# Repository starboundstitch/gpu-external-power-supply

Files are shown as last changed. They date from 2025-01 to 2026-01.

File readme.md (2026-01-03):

# GPU External Power Supply

The GPU External Power Supply is a project that aims to replace any computer graphics cards' power delivery system with a completely custom board. This repository contains all code, firmware, and schematics required to build the card as well as documentation on how it works.

The sister repository [geps-app](https://github.com/starboundstitch/geps-app) contains the code for the GUI application.

## Summary

The External GPU Power Card is a designed to seamlessly integrate with existing GPUs. It works by replacing the Vcore and Vmem rails with new power stages that have reduced noise, an increased voltage range, and an increased maximum current which should provide additional stability and performance benefits.

The power supply also allows full control of its voltage characteristics to provide unlimited overclocking potential. The device integrates with our companion application to provide real time monitoring and adjustment using a GUI interface, allowing more informed decisions in the overclocking process to extract as much performance as possible.
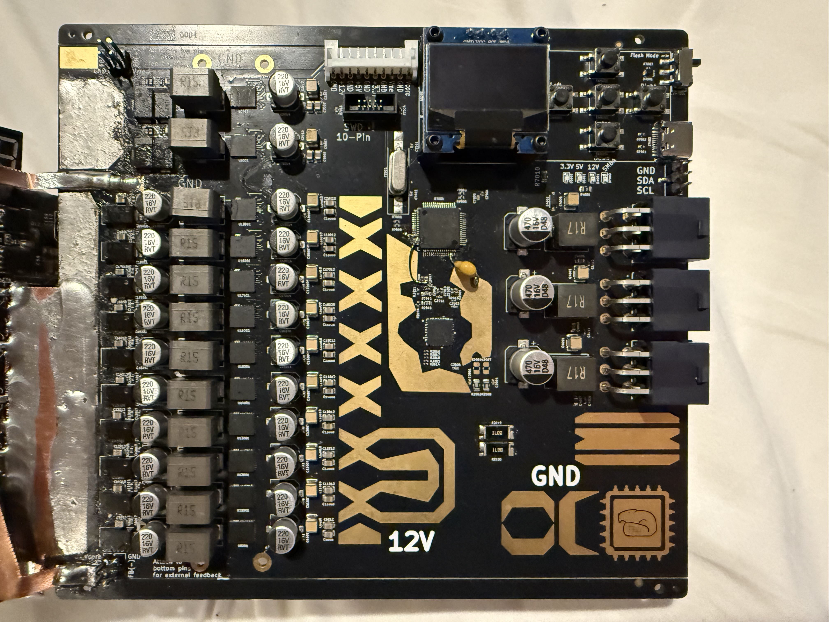
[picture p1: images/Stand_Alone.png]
Image of the device

<div align="center""> 
Prototype 2
</div>

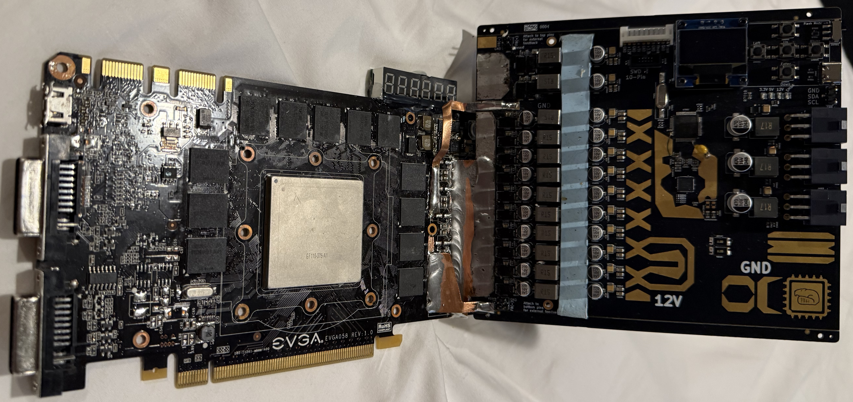
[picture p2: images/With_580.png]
Image of the device attached to a 580

<div align="center""> 
Prototype 2 is attached to a gtx 580
</div>

## Specs

* 12 Phases (10+2)
* Vcore
  * 0-2V
  * 500A Tested
  * 900A Theoretical
  * 10 Phases
* Vcore
  * 0-2.3V
  * 100A Tested
  * 180A Theoretical
  * 2 Phases

## Hardware

This section contains the KICAD project and all the associated files.

We make extensive use of hierarchy in this project and have the following schematics:
* Vcore_stage
  * Single MOSFET that connects to the VRM Controller Vcore Channel
* Vmem_stage
  * Single MOSFET that connects to the VRM Controller Vmem Channel
* VRM_Controller
  * VRM Controller with required pinouts and filtering
* 12V_Supply
  * Input filtering and connectors
* Low_Current_Supply
  * 3.3V & 5V buck converters and LED status
* Onboard_Control
  * Buttons and Display
* U_Controller
  * Microcontroller and required connectors (including USB-C)

## Firmware

This section contains all micro-controller code and is using the rust language with the [stmf4XX-hal](https://github.com/stm32-rs/stm32f4xx-hal) library.

> [!CAUTION]
> The stm32f401RE that is used does NOT have enough SRAM to run in debug mode and it will NOT flash.

The controller should automatically build and flash with:

```
cargo run --release
```

Additionally, in the future we will support flashing via USB DFU mode (instructions TBD).

## License

All the code and hardware files in this repository are licensed according to the GPLv3 in the [LICENSE](https://github.com/starboundstitch/gpu-external-power-supply/blob/master/LICENSE) file.

In addition, many of the symbols and footprints are provided by the manufacturers for use and are thus liable under the manufactures' licenses.

This project was created by [@Xunnin](https://github.com/Xunnin), [@starboundstitch](https://github.com/starboundstitch), and [@StefClef](https://github.com/StefClef).

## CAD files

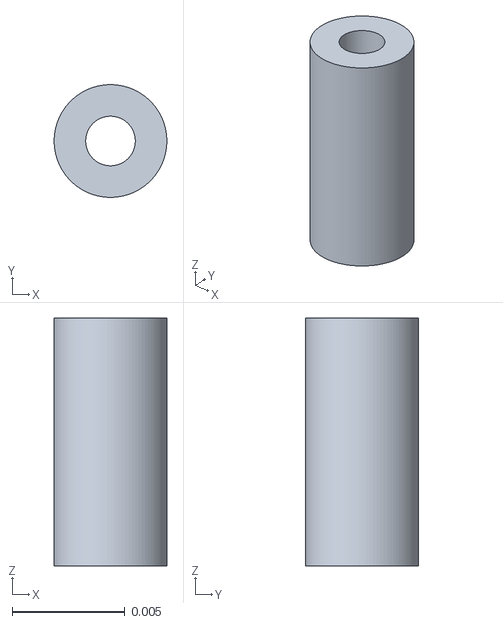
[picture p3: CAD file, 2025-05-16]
prints/DisplayColumn.stl
0.005 x 0.005 x 0.011

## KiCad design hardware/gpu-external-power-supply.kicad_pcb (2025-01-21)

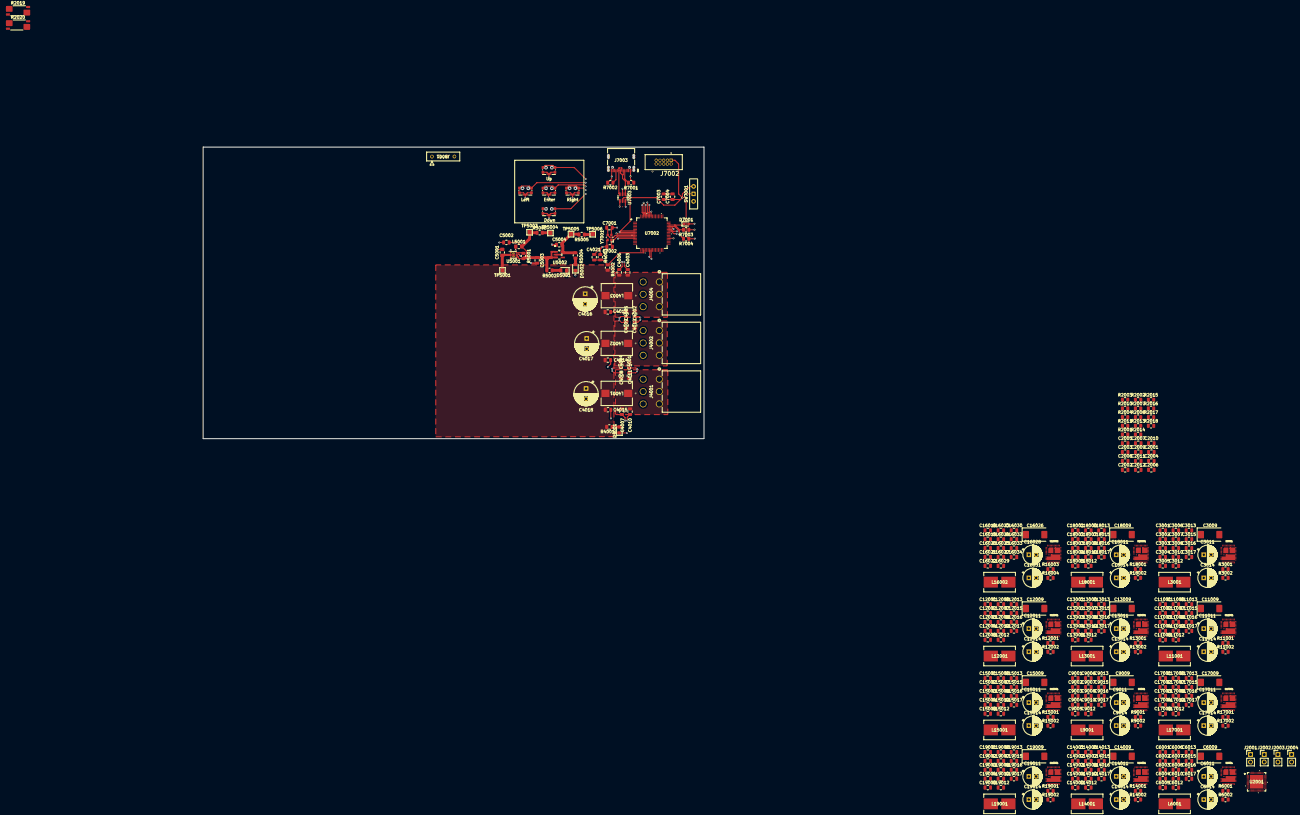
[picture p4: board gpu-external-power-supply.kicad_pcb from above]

Board: 6 copper layers, 170.2 x 99.1 mm, 354 parts (0 on the bottom side), 141 nets.

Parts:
C2001, C2004: 1nF; C_0805_2012Metric
C2002, C2010, C2011, C2012, C5003, C5004: 1uF; C_0805_2012Metric
C2003, C2005: 100pF; C_0805_2012Metric
C2006, C3003, C3006, C3007, C3017, C6003, C6006, C6007, C6017, C9003, C9006, C9007, C9017, C11003, C11006, C11007, C11017, C12003, C12006, C12007, C12017, C13003, C13006, C13007, C13017, C14003, C14006, C14007, C14017, C15003, C15006, C15007, C15017, C16020, C16023, C16024, C16034, C17003, C17006, C17007, C17017, C18003, C18006, C18007, C18017, C19003, C19006, C19007, C19017: 0.1uF; C_0805_2012Metric
C2007, C3016, C6016, C9016, C11016, C12016, C13016, C14016, C15016, C16033, C17016, C18016, C19016: 4.7uF; C_0805_2012Metric
C2008, C2009: 2200pF; C_0805_2012Metric
C3001, C3005, C6001, C6005, C9001, C9005, C11001, C11005, C12001, C12005, C13001, C13005, C14001, C14005, C15001, C15005, C16018, C16022, C17001, C17005, C18001, C18005, C19001, C19005: 47pF; C_0805_2012Metric
C3002, C3004, C6002, C6004, C9002, C9004, C11002, C11004, C12002, C12004, C13002, C13004, C14002, C14004, C15002, C15004, C16019, C16021, C17002, C17004, C18002, C18004, C19002, C19004: 2.2uF; C_0805_2012Metric
C3008, C3010, C3012, C3015, C5002, C6008, C6010, C6012, C6015, C9008, C9010, C9012, C9015, C11008, C11010, C11012, C11015, C12008, C12010, C12012, C12015, C13008, C13010, C13012, C13015, C14008, C14010, C14012, C14015, C15008, C15010, C15012, C15015, C16025, C16027, C16029, C16032, C17008, C17010, C17012, C17015, C18008, C18010, C18012, C18015, C19008, C19010, C19012, C19015: 22uF; C_0805_2012Metric
C3009, C6009, C9009, C11009, C12009, C13009, C14009, C15009, C16026, C17009, C18009, C19009: 470uF; CP_EIA-7343-40_Kemet-Y
C3011, C3014, C6011, C6014, C9011, C9014, C11011, C11014, C12011, C12014, C13011, C13014, C14011, C14014, C15011, C15014, C16028, C16031, C17011, C17014, C18011, C18014, C19011, C19014: 220uF; CP_Radial_D6.3mm_P2.50mm
C3013, C6013, C9013, C11013, C12013, C13013, C14013, C15013, C16030, C17013, C18013, C19013: 47uF; C_0805_2012Metric
C4001, C4002, C4003: 470u; C_0805_2012Metric
C4004, C4005, C4006: 47u; C_0805_2012Metric
C4007, C4008, C4009: 10u; C_0805_2012Metric
C4010, C4011, C4012, C4021: 0.1u; C_0805_2012Metric
C4013, C4014, C4015: 330u; C_0805_2012Metric
C4016, C4017, C4018: 470u; CP_Radial_D8.0mm_P3.50mm
C5001: 10uF; C_0805_2012Metric_Pad1.18x1.45mm_HandSolder
C7001, C7002: 6pF; C_0805_2012Metric
C7003: 4.7u; C_0805_2012Metric
C7004: 100n; C_0805_2012Metric
D4001, D5001, D5002: 150080SS75000; LED_0805_2012Metric_Pad1.15x1.40mm_HandSolder
D7001: GG060303100N2P; D_0603_1608Metric
J2001, J2002, J2003, J2004: Conn_01x02_Pin; PinHeader_1x02_P2.54mm_Vertical
J4001, J4002, J4004: 353180620; CONN_35318-06xx_MOL
J7002: Conn_ARM_JTAG_SWD_10; CNC_3221-10-0100-00
J7003: USB_C_Receptacle_USB2.0_16P; 12402012E212A_AMP
J8001: Conn_01x04_Pin; CONN_PPTC041LFBN-RC_SUL
L3001, L6001, L9001, L11001, L12001, L13001, L14001, L15001, L16002, L17001, L18001, L19001: 150nH; IND_IHVR-4025JZ-3Z_VIS
L4001, L4002, L4003: 170nH; IND_IFLR4031GCERR17M01_VIS-L
L5001: 2.2uH; L_0805_2012Metric_Pad1.15x1.40mm_HandSolder
R2001, R2002, R2007, R2008, R2013, R2014, R2015, R2016, R2017, R2018, R4002: 10k; R_0805_2012Metric
R2003: 130k; R_0805_2012Metric
R2004, R2011: 37.4k; R_0805_2012Metric
R2010: 2430k; R_0805_2012Metric
R2019, R2020: 1m; R_Shunt_Vishay_WSK2512_6332Metric_T1.19mm
R3001, R6001, R9001, R11001, R12001, R13001, R14001, R15001, R16003, R17001, R18001, R19001: 2.2; R_0805_2012Metric
R3002, R6002, R9002, R11002, R12002, R13002, R14002, R15002, R16004, R17002, R18002, R19002: 0; R_0805_2012Metric
R4001: 337; R_0805_2012Metric
R4003: 3.5k; R_0805_2012Metric
R5001, R7004: 100k; R_0805_2012Metric
R5002: 100+-5; R_0805_2012Metric
R5003, R5005: 1; R_0805_2012Metric
R5004: 45+-5; R_0805_2012Metric
R7001, R7002: 5K1; R_0805_2012Metric
R7003: 10K; R_0805_2012Metric
SW7001: SW_Wuerth_450301014042; SW_Slide-03_Wuerth-WS-SLTV_10x2.5x6.4_P2.54mm
SW8001, SW8002, SW8003, SW8004, SW8005: CK_KMS2xxG; SW_SPST_CK_KMS2xxGP
TP5001: 12V -> 5V; TestPoint_Pad_1.5x1.5mm
TP5003, TP5004, TP5005, TP5006: TestPoint; TestPoint_Pad_1.5x1.5mm
U2001: TPS536C7B1RSLT; QFN48_6X6_TEX
U3001, U6001, U9001, U11001, U12001, U13001, U14001, U15001, U16002, U17001, U18001, U19001: AOZ5276QI
U5001: TPS62160DSG; WSON-8-1EP_2x2mm_P0.5mm_EP0.9x1.6mm_ThermalVias
U5002: TPS73633DBVR; DBV5
U7002: STM32C071RBT6; LQFP-64_STM
U7003: USBLC6-2SC6; SOT-23-6
Y7001: Crystal_GND24; Crystal_SMD_Abracon_ABM10-4Pin_2.5x2.0mm

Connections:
3.3V: C2006.1, C2007.1, C7003.1, C7004.1, J7002.1 (VTref), J8001.2, R2001.1, R2007.1, R2013.1, R2014.1, R2015.1, R2016.1, R2017.1, R2018.1, R5005.2, R7004.1, SW7001.3 (A), TP5006.1, U2001.47 (VCC), U7002.7 (VREF+), U7002.8 (VDD/VDDA), U7003.5 (VBUS)
5V: R5003.2, TP5004.1
12V: C4013.1, C4014.1, C4015.1, C4016.1, C4017.1, C4018.1, C5001.1, L4001.2, L4002.2, L4003.2, R4001.1, R4002.1, TP5001.1, U5001.2 (VIN), U5001.3 (EN)
12V_VOL_SENS: C4021.1, R4002.2, R4003.1, U7002.19 (PA2)
/5v: C3002.1, C6002.1, C9002.1, C11002.1, C12002.1, C13002.1, C14002.1, C15002.1, C16019.1, C17002.1, C18002.1, C19002.1, R3001.1, R6001.1, R9001.1, R11001.1, R12001.1, R13001.1, R14001.1, R15001.1, R16003.1, R17001.1, R18001.1, R19001.1, U3001.4 (PVCC), U3001.35 (EN), U6001.4 (PVCC), U6001.35 (EN), U9001.4 (PVCC), U9001.35 (EN), U11001.4 (PVCC), U11001.35 (EN), U12001.4 (PVCC), U12001.35 (EN), U13001.4 (PVCC), U13001.35 (EN), U14001.4 (PVCC), U14001.35 (EN), U15001.4 (PVCC), U15001.35 (EN), U16002.4 (PVCC), U16002.35 (EN), U17001.4 (PVCC), U17001.35 (EN), U18001.4 (PVCC), U18001.35 (EN), U19001.4 (PVCC), U19001.35 (EN)
/U Controller/PF0: C7001.2, U7002.10 (PF0-OSC_IN), Y7001.3
/U Controller/PF1: C7002.2, U7002.11 (PF1-OSC_OUT), Y7001.1
/VRM Controller/ADDR_CONFIG: R2010.2, R2011.1, U2001.42 (ADDR_CONFIG)
/VRM Controller/CSNIN: C2011.2, C2012.1, C3007.1, C3008.1, C3010.1, C3012.1, C3014.1, C6007.1, C6008.1, C6010.1, C6012.1, C6014.1, C9007.1, C9008.1, C9010.1, C9012.1, C9014.1, C11007.1, C11008.1, C11010.1, C11012.1, C11014.1, C12007.1, C12008.1, C12010.1, C12012.1, C12014.1, C13007.1, C13008.1, C13010.1, C13012.1, C13014.1, C14007.1, C14008.1, C14010.1, C14012.1, C14014.1, C15007.1, C15008.1, C15010.1, C15012.1, C15014.1, C16024.1, C16025.1, C16027.1, C16029.1, C16031.1, C17007.1, C17008.1, C17010.1, C17012.1, C17014.1, C18007.1, C18008.1, C18010.1, C18012.1, C18014.1, C19007.1, C19008.1, C19010.1, C19012.1, C19014.1, R2019.1, R2020.2, U2001.46 (VIN_CSNIN), U3001.25 (VIN), U3001.30 (VIN), U6001.25 (VIN), U6001.30 (VIN), U9001.25 (VIN), U9001.30 (VIN), U11001.25 (VIN), U11001.30 (VIN), U12001.25 (VIN), U12001.30 (VIN), U13001.25 (VIN), U13001.30 (VIN), U14001.25 (VIN), U14001.30 (VIN), U15001.25 (VIN), U15001.30 (VIN), U16002.25 (VIN), U16002.30 (VIN), U17001.25 (VIN), U17001.30 (VIN), U18001.25 (VIN), U18001.30 (VIN), U19001.25 (VIN), U19001.30 (VIN)
/VRM Controller/CSPIN: C2010.1, C2011.1, R2019.2, R2020.1, U2001.45 (CSPIN)
/VRM Controller/CUR_A_9: C18001.1, U2001.35 (ACSP9), U18001.38 (IMON)
/VRM Controller/Cur_A_1: C6001.1, U2001.27 (ACSP1), U6001.38 (IMON)
/VRM Controller/Cur_A_2: C11001.1, U2001.28 (ACSP2), U11001.38 (IMON)
/VRM Controller/Cur_A_3: C12001.1, U2001.29 (ACSP3), U12001.38 (IMON)
/VRM Controller/Cur_A_4: C13001.1, U2001.30 (ACSP4), U13001.38 (IMON)
/VRM Controller/Cur_A_5: C14001.1, U2001.31 (ACSP5), U14001.38 (IMON)
/VRM Controller/Cur_A_6: C15001.1, U2001.32 (ACSP6), U15001.38 (IMON)
/VRM Controller/Cur_A_7: C16018.1, U2001.33 (ACSP7), U16002.38 (IMON)
/VRM Controller/Cur_A_8: C17001.1, U2001.34 (ACSP8), U17001.38 (IMON)
/VRM Controller/Cur_A_10: C19001.1, U2001.36 (ACSP10), U19001.38 (IMON)
/VRM Controller/Cur_B_1: C3001.1, U2001.38 (BCSP1), U3001.38 (IMON)
/VRM Controller/Cur_B_2: C9001.1, U2001.37 (BCSP2), U9001.38 (IMON)
/VRM Controller/PWM_A_1: U2001.12 (APWM1), U6001.34 (PWM)
/VRM Controller/PWM_A_2: U2001.11 (APWM2), U11001.34 (PWM)
/VRM Controller/PWM_A_3: U2001.10 (APWM3), U12001.34 (PWM)
/VRM Controller/PWM_A_4: U2001.9 (APWM4), U13001.34 (PWM)
/VRM Controller/PWM_A_5: U2001.8 (APWM5), U14001.34 (PWM)
/VRM Controller/PWM_A_6: U2001.7 (APWM6), U15001.34 (PWM)
/VRM Controller/PWM_A_7: U2001.6 (APWM7), U16002.34 (PWM)
/VRM Controller/PWM_A_8: U2001.5 (APWM8), U17001.34 (PWM)
/VRM Controller/PWM_A_9: U2001.4 (APWM9), U18001.34 (PWM)
/VRM Controller/PWM_A_10: U2001.3 (APWM10), U19001.34 (PWM)
/VRM Controller/PWM_B_1: U2001.1 (BPWM1), U3001.34 (PWM)
/VRM Controller/PWM_B_2: U2001.2 (BPWM2), U9001.34 (PWM)
/VRM Controller/VBOOT_A: R2003.2, R2004.1, U2001.18 (VBOOT_CHA)
/VRM Controller/VREF: C2002.2, C3001.2, C3003.1, C6001.2, C6003.1, C9001.2, C9003.1, C11001.2, C11003.1, C12001.2, C12003.1, C13001.2, C13003.1, C14001.2, C14003.1, C15001.2, C15003.1, C16018.2, C16020.1, C17001.2, C17003.1, C18001.2, C18003.1, C19001.2, C19003.1, R2003.1, R2010.1, U2001.48 (VREF), U3001.39 (REFIN), U6001.39 (REFIN), U9001.39 (REFIN), U11001.39 (REFIN), U12001.39 (REFIN), U13001.39 (REFIN), U14001.39 (REFIN), U15001.39 (REFIN), U16002.39 (REFIN), U17001.39 (REFIN), U18001.39 (REFIN), U19001.39 (REFIN)
AVR_READY: R2015.2, U2001.16 (AVR_RDY), U7002.38 (PC6)
A_ENABLE: C2001.1, R2001.2, R2002.1, U2001.17 (AVR_EN), U7002.49 (PC9)
B_ENABLE: C2004.1, R2007.2, R2008.1, U2001.19 (BVR_EN_/_RESET#_/_SYNC), U7002.64 (PC10)
CORE_TEMO: C2009.1, U2001.43 (BTSEN_/_ATSEN_/_TSEN)
CORE_TEMP: C6005.1, C11005.1, C12005.1, C13005.1, C14005.1, C15005.1, C16022.1, C17005.1, C18005.1, C19005.1, U6001.36 (TMON), U11001.36 (TMON), U12001.36 (TMON), U13001.36 (TMON), U14001.36 (TMON), U15001.36 (TMON), U16002.36 (TMON), U17001.36 (TMON), U18001.36 (TMON), U19001.36 (TMON)
GND: C2001.2, C2002.1, C2004.2, C2006.2, C2007.2, C2008.2, C2009.2, C2010.2, C2012.2, C3002.2, C3003.2, C3004.2, C3005.2, C3007.2, C3008.2, C3009.2, C3010.2, C3011.2, C3012.2, C3013.2, C3014.2, C3015.2, C3016.2, C3017.2, C4001.2, C4002.2, C4003.2, C4004.2, C4005.2, C4006.2, C4007.2, C4008.2, C4009.2, C4010.2, C4011.2, C4012.2, C4013.2, C4014.2, C4015.2, C4016.2, C4017.2, C4018.2, C4021.2, C5001.2, C5002.2, C5003.2, C5004.2, C6002.2, C6003.2, C6004.2, C6005.2, C6007.2, C6008.2, C6009.2, C6010.2, C6011.2, C6012.2, C6013.2, C6014.2, C6015.2, C6016.2, C6017.2, C7001.1, C7002.1, C7003.2, C7004.2, C9002.2, C9003.2, C9004.2, C9005.2, C9007.2, C9008.2, C9009.2, C9010.2, C9011.2, C9012.2, C9013.2, C9014.2, C9015.2, C9016.2, C9017.2, C11002.2, C11003.2, C11004.2, C11005.2, C11007.2, C11008.2, C11009.2, C11010.2, C11011.2, C11012.2, C11013.2, C11014.2, C11015.2, C11016.2, C11017.2, C12002.2, C12003.2, C12004.2, C12005.2, C12007.2, C12008.2, C12009.2, C12010.2, C12011.2, C12012.2, C12013.2, C12014.2, C12015.2, C12016.2, C12017.2, C13002.2, C13003.2, C13004.2, C13005.2, C13007.2, C13008.2, C13009.2, C13010.2, C13011.2, C13012.2, C13013.2, C13014.2, C13015.2, C13016.2, C13017.2, C14002.2, C14003.2, C14004.2, C14005.2, C14007.2, C14008.2, C14009.2, C14010.2, C14011.2, C14012.2, C14013.2, C14014.2, C14015.2, C14016.2, C14017.2, C15002.2, C15003.2, C15004.2, C15005.2, C15007.2, C15008.2, C15009.2, C15010.2, C15011.2, C15012.2, C15013.2, C15014.2, C15015.2, C15016.2, C15017.2, C16019.2, C16020.2, C16021.2, C16022.2, C16024.2, C16025.2, C16026.2, C16027.2, C16028.2, C16029.2, C16030.2, C16031.2, C16032.2, C16033.2, C16034.2, C17002.2, C17003.2, C17004.2, C17005.2, C17007.2, C17008.2, C17009.2, C17010.2, C17011.2, C17012.2, C17013.2, C17014.2, C17015.2, C17016.2, C17017.2, C18002.2, C18003.2, C18004.2, C18005.2, C18007.2, C18008.2, C18009.2, C18010.2, C18011.2, C18012.2, C18013.2, C18014.2, C18015.2, C18016.2, C18017.2, C19002.2, C19003.2, C19004.2, C19005.2, C19007.2, C19008.2, C19009.2, C19010.2, C19011.2, C19012.2, C19013.2, C19014.2, C19015.2, C19016.2, C19017.2, D4001.1 (K), D5001.1 (K), D5002.1 (K), D7001.2 (A), J2002.2, J2004.2, J4001.2, J4001.4, J4001.6, J4002.2, J4002.4, J4002.6, J4004.2, J4004.4, J4004.6, J7002.3 (GND), J7002.5 (GND), J7002.9 (GNDDetect), J7003.A1 (GND), J7003.B1 (GND), J7003.S1 (SHIELD), J8001.1, R2002.2, R2004.2, R2008.2, R2011.2, R4003.2, R7001.2, R7002.2, R7003.1, SW7001.2 (C), SW8001.1, SW8001.SH (B), SW8002.1, SW8002.SH (B), SW8003.1, SW8003.SH (B), SW8004.1, SW8004.SH (B), SW8005.1, SW8005.SH (B), U2001.49 (GND), U3001.2 (AGND), U3001.5 (PGND), U3001.20 (PGND), U3001.40 (PGND), U5001.1 (PGND), U5001.4 (AGND), U5001.5 (FB), U5001.9 (PAD), U5002.2 (GND), U6001.2 (AGND), U6001.5 (PGND), U6001.20 (PGND), U6001.40 (PGND), U7002.9 (VSS/VSSA), U7003.2 (GND), U9001.2 (AGND), U9001.5 (PGND), U9001.20 (PGND), U9001.40 (PGND), U11001.2 (AGND), U11001.5 (PGND), U11001.20 (PGND), U11001.40 (PGND), U12001.2 (AGND), U12001.5 (PGND), U12001.20 (PGND), U12001.40 (PGND), U13001.2 (AGND), U13001.5 (PGND), U13001.20 (PGND), U13001.40 (PGND), U14001.2 (AGND), U14001.5 (PGND), U14001.20 (PGND), U14001.40 (PGND), U15001.2 (AGND), U15001.5 (PGND), U15001.20 (PGND), U15001.40 (PGND), U16002.2 (AGND), U16002.5 (PGND), U16002.20 (PGND), U16002.40 (PGND), U17001.2 (AGND), U17001.5 (PGND), U17001.20 (PGND), U17001.40 (PGND), U18001.2 (AGND), U18001.5 (PGND), U18001.20 (PGND), U18001.40 (PGND), U19001.2 (AGND), U19001.5 (PGND), U19001.20 (PGND), U19001.40 (PGND), Y7001.2, Y7001.4
I2C_SCL: J8001.3, U7002.24 (PA7)
I2C_SDA: J8001.4, U7002.23 (PA6)
MEM_TEMP: C2008.1, C3005.1, C9005.1, U2001.44 (ATSEN_/_BTSEN), U3001.36 (TMON), U9001.36 (TMON)
NRST: J7002.10 (~RESET), U7002.12 (PF2-NRST)
unnamed: C3006.1, R3002.2
unnamed: C3006.2, U3001.31 (PHASE), U3001.32 (PHASE)
unnamed: C4001.1, C4004.1, C4007.1, C4010.1, J4001.1, J4001.3, J4001.5, L4001.1
unnamed: C4002.1, C4005.1, C4008.1, C4011.1, J4002.1, J4002.3, J4002.5, L4002.1
unnamed: C4003.1, C4006.1, C4009.1, C4012.1, J4004.1, J4004.3, J4004.5, L4003.1
unnamed: C6006.1, R6002.2
unnamed: C6006.2, U6001.31 (PHASE), U6001.32 (PHASE)
unnamed: C9006.1, R9002.2
unnamed: C9006.2, U9001.31 (PHASE), U9001.32 (PHASE)
unnamed: C11006.1, R11002.2
unnamed: C11006.2, U11001.31 (PHASE), U11001.32 (PHASE)
unnamed: C12006.1, R12002.2
unnamed: C12006.2, U12001.31 (PHASE), U12001.32 (PHASE)
unnamed: C13006.1, R13002.2
unnamed: C13006.2, U13001.31 (PHASE), U13001.32 (PHASE)
unnamed: C14006.1, R14002.2
unnamed: C14006.2, U14001.31 (PHASE), U14001.32 (PHASE)
unnamed: C15006.1, R15002.2
unnamed: C15006.2, U15001.31 (PHASE), U15001.32 (PHASE)
unnamed: C16023.1, R16004.2
unnamed: C16023.2, U16002.31 (PHASE), U16002.32 (PHASE)
unnamed: C17006.1, R17002.2
unnamed: C17006.2, U17001.31 (PHASE), U17001.32 (PHASE)
unnamed: C18006.1, R18002.2
unnamed: C18006.2, U18001.31 (PHASE), U18001.32 (PHASE)
unnamed: C19006.1, R19002.2
unnamed: C19006.2, U19001.31 (PHASE), U19001.32 (PHASE)
unnamed: D4001.2 (A), R4001.2
unnamed: D5001.2 (A), R5002.2
unnamed: D5002.2 (A), R5004.2
unnamed: C2005.1, J2001.1, U2001.25 (AVSP)
unnamed: C2003.1, J2003.1, U2001.40 (BVSP)
unnamed: C2003.2, J2004.1, U2001.39 (BVSN)
unnamed: J7003.A5 (CC1), R7001.1
unnamed: J7003.B5 (CC2), R7002.1
unnamed: J7003.A6 (D+), J7003.B6 (D+), U7003.3 (I/O2)
unnamed: J7003.A7 (D-), J7003.B7 (D-), U7003.1 (I/O1)
unnamed: J7003.A4 (VBUS), J7003.B4 (VBUS)
unnamed: L3001.1, U3001.10 (VSWH)
unnamed: L6001.1, U6001.10 (VSWH)
unnamed: L9001.1, U9001.10 (VSWH)
unnamed: L11001.1, U11001.10 (VSWH)
unnamed: L12001.1, U12001.10 (VSWH)
unnamed: L13001.1, U13001.10 (VSWH)
unnamed: L14001.1, U14001.10 (VSWH)
unnamed: L15001.1, U15001.10 (VSWH)
unnamed: L16002.1, U16002.10 (VSWH)
unnamed: L17001.1, U17001.10 (VSWH)
unnamed: L18001.1, U18001.10 (VSWH)
unnamed: L19001.1, U19001.10 (VSWH)
unnamed: C2005.2, U2001.26 (AVSN)
unnamed: R3002.1, U3001.33 (BOOT)
unnamed: C3004.1, R3001.2, U3001.3 (VCC)
unnamed: R5001.1, U5001.8 (PG)
unnamed: L5001.1, U5001.7 (SW)
unnamed: C5002.1, C5003.1, L5001.2, R5001.2, R5002.1, R5003.1, TP5003.1, U5001.6 (VOS), U5002.1 (IN), U5002.3 (EN)
unnamed: C5004.1, R5004.1, R5005.1, TP5005.1, U5002.5 (OUT)
unnamed: R6002.1, U6001.33 (BOOT)
unnamed: C6004.1, R6001.2, U6001.3 (VCC)
unnamed: R9002.1, U9001.33 (BOOT)
unnamed: C9004.1, R9001.2, U9001.3 (VCC)
unnamed: R11002.1, U11001.33 (BOOT)
unnamed: C11004.1, R11001.2, U11001.3 (VCC)
unnamed: R12002.1, U12001.33 (BOOT)
unnamed: C12004.1, R12001.2, U12001.3 (VCC)
unnamed: R13002.1, U13001.33 (BOOT)
unnamed: C13004.1, R13001.2, U13001.3 (VCC)
unnamed: R14002.1, U14001.33 (BOOT)
unnamed: C14004.1, R14001.2, U14001.3 (VCC)
unnamed: R15002.1, U15001.33 (BOOT)
unnamed: C15004.1, R15001.2, U15001.3 (VCC)
unnamed: R16004.1, U16002.33 (BOOT)
unnamed: C16021.1, R16003.2, U16002.3 (VCC)
unnamed: R17002.1, U17001.33 (BOOT)
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

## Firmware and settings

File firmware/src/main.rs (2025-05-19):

#![no_main]
#![no_std]

use cortex_m_rt::entry;

use stm32f4xx_hal::{self as hal, gpio::PinState, i2c::I2c, pac, prelude::*};

use stm32f4xx_hal::otg_fs::{UsbBus, USB};
use usb_device::prelude::*;

use embedded_graphics::{
    mono_font::{ascii::FONT_9X18, MonoTextStyle, MonoTextStyleBuilder},
    pixelcolor::BinaryColor,
    prelude::*,
    primitives::{PrimitiveStyle, Rectangle},
    text::{Baseline, Text},
};
use ssd1306::{prelude::*, I2CDisplayInterface, Ssd1306};

use lexical_core::BUFFER_SIZE;

use defmt;
use defmt_rtt as _;

use panic_semihosting as _; // Sends Backtraces through Probe-rs

use navigation::Navigation;
use usbd_serial::embedded_io::{ReadReady, WriteReady};
use vrm_controller::TPSC536C7;
mod navigation;
mod vrm_controller;

static mut EP_MEMORY: [u32; 1024] = [0; 1024];

#[entry]
fn main() -> ! {
    defmt::info!("System Starting");

    //** Microcontroller Configuration **//
    let dp = pac::Peripherals::take().expect("Cannot Take Peripherals");
    let rcc = dp.RCC.constrain();
    let clocks = rcc
        .cfgr
        .use_hse(8.MHz())
        .sysclk(48.MHz())
        .require_pll48clk()
        .freeze();

    //** Declare GPIOs **//
    let gpioa = dp.GPIOA.split();
    let gpiob = dp.GPIOB.split();
    let gpioc = dp.GPIOC.split();
    let gpiod = dp.GPIOD.split();
    let mut led = gpioa.pa5.into_push_pull_output();

    //** Enable VRM Controller Pins **//
    let _avr_ready = gpioc.pc1.into_floating_input();
    let _bvr_ready = gpioc.pc2.into_floating_input();
    let _b_enable = gpioc.pc10.into_push_pull_output_in_state(PinState::High);

    //** Enable Onboard Control Pins **//
    let up = gpioc.pc6.into_pull_up_input();
    let down = gpiob.pb12.into_pull_up_input();
    let enter = gpiob.pb14.into_pull_up_input();
    let right = gpiob.pb13.into_pull_up_input();
    let left = gpiob.pb15.into_pull_up_input();

    // Read Boot Pins

    //** I2C Configuration **//

    // I2C Channel 1
    let sda1 = gpiob.pb7;
    let scl1 = gpiob.pb6;
    let i2c1 = I2c::new(
        dp.I2C1,
        (scl1, sda1),
        hal::i2c::Mode::standard(400.kHz()),
        &clocks,
    );

    // I2C Channel 2
    let sda2 = gpioc.pc9;
    let scl2 = gpioa.pa8;
    let i2c2 = I2c::new(
        dp.I2C3,
        (scl2, sda2),
        hal::i2c::Mode::standard(400.kHz()),
        &clocks,
    );

    //** VRM Controller Initialization **//
    let i2c_addr = 0x5F;

    // Create Controller
    let mut controller = vrm_controller::TPSC536C7::new(i2c1, i2c_addr);
    defmt::info!("Past VRM Controller Init");

    //** Display Configuration **//
    // I2C interface
    let interface = I2CDisplayInterface::new(i2c2);

    // Configure the display
    let mut display = Ssd1306::new(interface, DisplaySize128x64, DisplayRotation::Rotate0)
        .into_buffered_graphics_mode();
    display.init().unwrap();

    defmt::info!("Past Display Init");

    // Font and text color from the embedded_graphics library
    let text_style = MonoTextStyleBuilder::new()
        .font(&FONT_9X18)
        .text_color(BinaryColor::On)
        .build();
    let text_style_inv = MonoTextStyleBuilder::new()
        .font(&FONT_9X18)
        .text_color(BinaryColor::Off)
        .build();

    // Fill
    let fill = PrimitiveStyle::with_fill(BinaryColor::Off);
    let fill_inv = PrimitiveStyle::with_fill(BinaryColor::On);
    let hollow = PrimitiveStyle::with_stroke(BinaryColor::On, 1);

    // GUI Text
    Text::with_baseline("   Vcore Vmem", Point::zero(), text_style, Baseline::Top)
        .draw(&mut display)
        .unwrap();
    Text::with_baseline("V:", Point::new(0, 16), text_style, Baseline::Top)
        .draw(&mut display)
        .unwrap();
    Text::with_baseline("A:", Point::new(0, 32), text_style, Baseline::Top)
        .draw(&mut display)
        .unwrap();
    Text::with_baseline("T:", Point::new(0, 48), text_style, Baseline::Top)
        .draw(&mut display)
        .unwrap();

    // Flush Display
    display.flush().unwrap();

    defmt::info!("First Display Flush");

    let usb = USB::new(
        (dp.OTG_FS_GLOBAL, dp.OTG_FS_DEVICE, dp.OTG_FS_PWRCLK),
        (gpioa.pa11, gpioa.pa12),
        &clocks,
    );

    #[allow(static_mut_refs)] // Not My implementation
    let usb_bus = UsbBus::new(usb, unsafe { &mut EP_MEMORY });

    let mut serial = usbd_serial::SerialPort::new(&usb_bus);

    let mut usb_dev = UsbDeviceBuilder::new(&usb_bus, UsbVidPid(0x16c0, 0x27dd))
        .device_class(usbd_serial::USB_CLASS_CDC)
        .strings(&[StringDescriptors::default()
            .manufacturer("Overclocking Club")
            .product("gpu-external-power-supply")
            .serial_number("Prototype-1")])
        .unwrap()
        .build();

    defmt::info!("USB Initialized");

    // Timer Configuration
    let mut led_time = dp.TIM1.counter_ms(&clocks);
    let mut ui_time = dp.TIM3.counter_ms(&clocks);
    led_time.start(1000.millis()).unwrap();
    ui_time.start(100.millis()).unwrap();

    // Current State of Devices
    let mut nav = Navigation::default();
    let mut dev = navigation::Device::default();
    let mut updated_val: f32 = 10.;

    // Get Initial Values
    update_vrm_read(&mut dev, &mut controller);
    // Enable the device
    controller.ch_ab().on_off_config(0x00);
    // No Minimum Output Voltage
    controller.vout_min().write(0.);

    loop {
        let mut update_display = true;

        if led_time.wait().is_ok() {
            led.toggle();
        }

        // Code that Runs Periodically
        if ui_time.wait().is_ok() {
            // Button Input
            match nav.get_mode() {
                navigation::Mode::Navigation => {
                    if up.is_low() {
                        defmt::info!("Up");
                        nav.move_up();
                    } else if down.is_low() {
                        defmt::info!("Down");
                        nav.move_down();
                    } else if right.is_low() {
                        defmt::info!("Right");
                        nav.move_right();
                    } else if left.is_low() {
                        defmt::info!("Left");
                        nav.move_left();
                    } else if enter.is_low() {
                        defmt::info!("Enter");
                        if nav.get_position().1 == 2 {
                            continue;
                        }
                        nav.change_mode();

                        // temporary value that is being updated
                        updated_val = match nav.get_position() {
                            (0, 0) => dev.core().get_voltage_setpoint(),
                            (0, 1) => dev.core().get_current_limit(),
                            (0, 2) => dev.core().get_temperature(),
                            (1, 0) => dev.mem().get_voltage_setpoint(),
                            (1, 1) => dev.mem().get_current_limit(),
                            (1, 2) => dev.mem().get_temperature(),
                            (_, _) => 0., // Default condition that sound never match
                        };
                    } else {
                        update_display = false;
                    }
                }
                navigation::Mode::Update => {
                    let (step_small, step_large) = match nav.get_position() {
                        (_, 0) => (0.005, 0.1),
                        (_, 1) => (1., 10.),
                        (_, _) => (0., 0.),
                    };
                    if up.is_low() {
                        updated_val += step_small;
                    } else if down.is_low() {
                        updated_val -= step_small;
                    } else if right.is_low() {
                        updated_val += step_large;
                    } else if left.is_low() {
                        updated_val -= step_large;
                    } else if enter.is_low() {
                        nav.change_mode();

                        // Write Data to I2C and update dev voltages here
                        dev.store_value(nav.get_position(), updated_val);

                        match nav.get_position() {
                            (0, _) => {
                                controller.ch_a();
                            }
                            (1, _) => {
                                controller.ch_b();
                            }
                            (_, _) => (),
                        };
                        match nav.get_position() {
                            (_, 0) => controller.vout_command().write(updated_val),
                            (_, 1) => controller.iout_oc_fault_limit().write(updated_val),
                            (_, _) => (), // Default condition that sound never match
                        };
                    } else {
                        update_display = false;
                    }
                }
            }

            // Runs only if there is a value to update on the display to save on unnecessary write
            // cycles and full display clears
            // if update_display {
            // Updates the displays for all stored values
            // Vcore
            display_data(
                &mut display,
                text_style,
                fill,
                navigation::translate_point((0, 0)),
                dev.core().get_voltage(),
            );
            display_data(
                &mut display,
                text_style,
                fill,
                navigation::translate_point((0, 1)),
                dev.core().get_current(),
            );
            display_data(
                &mut display,
                text_style,
                fill,
                navigation::translate_point((0, 2)),
                dev.core().get_temperature(),
            );
            // Vmem
            display_data(
                &mut display,
                text_style,
                fill,
                navigation::translate_point((1, 0)),
                dev.mem().get_voltage(),
            );
            display_data(
                &mut display,
                text_style,
                fill,
                navigation::translate_point((1, 1)),
                dev.mem().get_current(),
            );
            display_data(
                &mut display,
                text_style,
                fill,
                navigation::translate_point((1, 2)),
                dev.mem().get_temperature(),
            );

            // Update Currently Hovered
            match nav.get_mode() {
                navigation::Mode::Navigation => {
                    Rectangle::new(nav.get_point(), Size::new(9 * 5, 16))
                        .into_styled(hollow)
                        .draw(&mut display)
                        .unwrap();
                }
                navigation::Mode::Update => {
                    display_data(
                        &mut display,
                        text_style_inv,
                        fill_inv,
                        nav.get_point(),
                        updated_val,
                    );
                }
            }

            display.flush().unwrap();

            // Read new I2C Values (at end so that it has the whole UI time for the values to
            // collect)
            update_vrm_read(&mut dev, &mut controller);

            // USB Handling
            if !usb_dev.poll(&mut [&mut serial]) {
                continue; // This means that the port cannot read or write currently
            }

            // USB to send values to computer
            if serial.write_ready().unwrap() {
                let mut slice = [0u8; 128];
                let length =
                    bincode::encode_into_slice(&dev, &mut slice, bincode::config::standard())
                        .unwrap();

                let slice = &slice[..length];

                let _ = serial.write(slice);
            }
        }

        // If no data to read, don't try read
        if !serial.read_ready().unwrap() {
            continue;
        }

        let mut buf = [0u8; 128];
        let count = match serial.read(&mut buf) {
            Ok(count) if count > 0 => {
                defmt::debug!("USB: Read {} Bytes", count);
                Some(count)
            }
            Err(UsbError::WouldBlock) => {
                defmt::error!("USB: Read Buffer Full");
                None
            }
            Err(err) => {
                defmt::error!("USB: Other Error");
                None
            }
            _ => None,
        };

        if count.is_some() {
            defmt::println!("USB_Data: {}", buf[0..count.unwrap()]);
        }

        // Valid Read
        if count.is_some() {
            // Set Channel
            match buf[0] & 1u8 {
                0 => {
                    // Channel A
                    controller.ch_a();
                }
                1 => {
                    // Channel B
                    controller.ch_b();
                }
                _ => {}
            }
            // Send Command to I2C Device
            match buf[0] & 0x02 {
                0x0 => {
                    // Write
                    controller.command(&buf[1..count.unwrap()]);
                }
                0x2 => {
                    // Read
                }
                _ => {}
            }
        }
    }
}

// Displays a floating point value in the 2x3 grid of values on the main display
fn display_data<I: embedded_hal::i2c::I2c, D: ssd1306::size::DisplaySize>(
    display: &mut Ssd1306<I2CInterface<I>, D, ssd1306::mode::BufferedGraphicsMode<D>>,
    text_style: MonoTextStyle<BinaryColor>,
    fill: PrimitiveStyle<BinaryColor>,
    point: Point,
    val: f32,
) {
    Rectangle::new(point, Size::new(9 * 5, 16))
        .into_styled(fill)
        .draw(display)
        .unwrap();

    // Parse Float Values
    let mut buf = [b'0'; BUFFER_SIZE];
    let num_chars = lexical_core::write(val, &mut buf);
    let mut num_chars: usize = num_chars.len().into();
    if num_chars > 5 {
        num_chars = 5;
    }

    // Write to Display
    Text::with_baseline(
        unsafe { core::str::from_utf8_unchecked(&(buf[..num_chars])) },
        point,
        text_style,
        Baseline::Top,
    )
    .draw(display)
    .unwrap();
}

// Clears the Display
fn clear_display<I: embedded_hal::i2c::I2c, D: ssd1306::size::DisplaySize>(
    display: &mut Ssd1306<I2CInterface<I>, D, ssd1306::mode::BufferedGraphicsMode<D>>,
    fill: PrimitiveStyle<BinaryColor>,
) {
    Rectangle::new(Point::new(0, 0), Size::new(128, 64))
        .into_styled(fill)
        .draw(display)
        .unwrap();
}

fn update_vrm_read<I: embedded_hal::i2c::I2c>(
    dev: &mut navigation::Device,
    controller: &mut TPSC536C7<I>,
) {
    // Get Values for Display
    // Voltage
    dev.core().set_voltage(controller.ch_a().read_vout());
    dev.mem().set_voltage(controller.ch_b().read_vout());
    // Temperature
    dev.core()
        .set_temperature(controller.ch_a().read_temperature_1());
    dev.mem()
        .set_temperature(controller.ch_b().read_temperature_1());
    // Current
    dev.core().set_current(controller.ch_a().read_iout());
    dev.mem().set_current(controller.ch_b().read_iout());
    // Voltage Setpoint
    dev.core()
        .set_voltage_setpoint(controller.ch_a().vout_command().read());
    dev.mem()
        .set_voltage_setpoint(controller.ch_b().vout_command().read());
    // Current Limit
    dev.core()
        .set_current_limit(controller.ch_a().iout_oc_fault_limit().read());
    dev.mem()
        .set_current_limit(controller.ch_b().iout_oc_fault_limit().read());
}

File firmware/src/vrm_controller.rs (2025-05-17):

use embedded_hal::i2c::Error;
use pmbus_types_rs::{slinear11, ulinear16};

pub struct TPSC536C7<I> {
    address: u8,
    i2c: I,
}

/// An abstracted way to generate i2c PMBUS Read Commands.

/// Self, Name, Command (u8), length (int), format (slinear or ulinear)
macro_rules! send_read {
    ($self:ident, $name:literal, $cmd:expr, $length:expr,  $format:ident) => {{
        let mut buf = [b'\0'; $length];
        match $self.i2c.write_read($self.address, &[$cmd], &mut buf) {
            Ok(_val) => defmt::trace!("{}_Read: {:#X}, {:#X}", $name, $cmd, buf),
            Err(val) => defmt::error!("{}_Read_Error: {:#X}, {}", $name, $cmd, val.kind()),
        }
        $format::to(to_u16(buf))
    }};
}

/// An abstracted way to generate i2c PMBUS Write Commands.

/// Self, Name, Command (u8), length (int), format (slinear or ulinear), data (float)
macro_rules! send_write {
    ($self:ident, $name:literal, $cmd:expr, $length:expr,  $format:ident, $data:expr) => {{
        let con = $format::from($data).to_be_bytes();

        let buf: &mut [u8] = &mut [0u8; $length + 1];
        buf[0..$length].copy_from_slice(&con[0..($length)]);
        buf[$length] = $cmd;
        buf.reverse();
        match $self.i2c.write($self.address, buf) {
            Ok(_val) => defmt::trace!("{}_Write: {}", $name, buf),
            Err(val) => defmt::error!("{}_Write_Error: {}", $name, val.kind()),
        }
    }};
}

/// An abstracted way to generate i2c PMBUS Commands.

/// Type (name but different) Name, Command (u8), length (int), format (slinear or ulinear)
macro_rules! build_command {
    ($type:ident, $name:literal, $cmd:expr, $length:expr,  $format:ident) => {
        pub struct $type<'a, I> {
            dev: &'a mut TPSC536C7<I>,
        }

        impl<'a, I: embedded_hal::i2c::I2c> $type<'a, I> {
            pub fn read(&mut self) -> f32 {
                let dev = &mut self.dev;
                send_read!(dev, $name, $cmd, $length, $format)
            }
            pub fn write(&mut self, val: f32) {
                let dev = &mut self.dev;
                send_write!(dev, $name, $cmd, $length, $format, val)
            }
        }
    };
}

build_command!(
    VOUTCommand,
    "VOutCommand",
    Command::VOUTCommand.to_address(),
    2,
    ulinear16
);
build_command!(
    VOUTMax,
    "VOutMax",
    Command::VOUTMax.to_address(),
    2,
    ulinear16
);
build_command!(
    VOUTMin,
    "VOutMin",
    Command::VOUTMin.to_address(),
    2,
    ulinear16
);
build_command!(
    IOUTOCFaultLimit,
    "IOutOCFaultLimit",
    Command::IoutOCFaultLimit.to_address(),
    2,
    slinear11
);

pub enum Command {
    Page,
    Operation,
    OnOffConfig,
    ClearFaults,
    VOUTCommand,
    VOUTMax,
    VOUTDroop,
    VOUTMin,
    FrequencySwitch,
    IoutOCFaultLimit,
    StatusByte,
    ReadIout,
    ReadVout,
    ReadTemperature1,
    StatusAll,
    StatusExtended,
}

impl Command {
    pub fn to_address(self) -> u8 {
        match self {
            Command::Page => 0x00,
            Command::Operation => 0x01,
            Command::OnOffConfig => 0x02,
            Command::ClearFaults => 0x03,
            Command::VOUTCommand => 0x21,
            Command::VOUTMax => 0x24,
            Command::VOUTDroop => 0x28,
            Command::VOUTMin => 0x2B,
            Command::FrequencySwitch => 0x33,
            Command::IoutOCFaultLimit => 0x46,
            Command::StatusByte => 0x78,
            Command::ReadVout => 0x8B,
            Command::ReadIout => 0x8C,
            Command::ReadTemperature1 => 0x8D,
            Command::StatusAll => 0xDB,
            Command::StatusExtended => 0xDD,
        }
    }
}

pub enum Page {
    ChannelA,
    ChannelB,
    Both,
}

impl Page {
    pub fn to_bits(self) -> u8 {
        match self {
            Page::ChannelA => 0x00,
            Page::ChannelB => 0x01,
            Page::Both => 0xFF,
        }
    }
}

impl<I: embedded_hal::i2c::I2c> TPSC536C7<I> {
    pub fn new(i2c: I, address: u8) -> TPSC536C7<I> {
        let controller = TPSC536C7 { address, i2c };
        return controller;
    }

    pub fn command(&mut self, data: &[u8]) {
        match self.i2c.write(self.address, data) {
            Ok(_val) => defmt::trace!("Write_OK: {}", data),
            Err(val) => defmt::error!("Write Error: {}", val.kind()),
        }
    }

    pub fn read(&mut self, cmd: u8, buf: &mut [u8]) {
        match self.i2c.write_read(self.address, &[cmd], buf) {
            Ok(_val) => defmt::trace!("Read_OK: {:#X}, {:#X}", cmd, buf),
            Err(val) => defmt::error!("Controller Read: {:#X}, {}", cmd, val.kind()),
        }
    }

    pub fn on_off_config(&mut self, val: u8) {
        self.command(&[Command::OnOffConfig.to_address(), val]);
    }

    // PAGING OPTIONS
    fn page(&mut self, ch: Page) -> &mut Self {
        self.command(&[Command::Page.to_address(), ch.to_bits()]);
        self
    }

    pub fn ch_a(&mut self) -> &mut Self {
        self.page(Page::ChannelA)
    }

    pub fn ch_b(&mut self) -> &mut Self {
        self.page(Page::ChannelB)
    }

    pub fn ch_ab(&mut self) -> &mut Self {
        self.page(Page::Both)
    }

    pub fn clear_faults(&mut self) {
        self.command(&[Command::ClearFaults.to_address()]);
    }

    pub fn status_byte(&mut self) {
        let mut buf = [b'\0'; 1];
        self.read(Command::StatusByte.to_address(), &mut buf);
    }

    pub fn read_page(&mut self) {
        let mut buf = [b'\0'; 1];
        self.read(Command::Page.to_address(), &mut buf);
    }

    pub fn read_status_extended(&mut self) {
        let mut buf = [b'\0'; 7];
        self.read(Command::StatusExtended.to_address(), &mut buf);
    }

    pub fn read_status_all(&mut self) {
        let mut buf = [b'\0'; 18];
        self.read(Command::StatusAll.to_address(), &mut buf);
    }

    // READ WRITE COMMANDS
    /// Reads / Writes to the voltage output setpoint for the paged channel
    pub fn vout_command(&mut self) -> VOUTCommand<I> {
        VOUTCommand { dev: self }
    }

    /// Reads / Writes to the voltage max for the paged channel
    pub fn vout_max(&mut self) -> VOUTMax<I> {
        VOUTMax { dev: self }
    }

    /// Reads / Writes to the voltage min for the paged channel
    pub fn vout_min(&mut self) -> VOUTMin<I> {
        VOUTMin { dev: self }
    }

    /// Reads / Writes to the current output setpoint for the paged channel
    ///
    /// Is phased (can read the individual phases and set individual phase)
    /// values if we want to implement that
    pub fn iout_oc_fault_limit(&mut self) -> IOUTOCFaultLimit<I> {
        IOUTOCFaultLimit { dev: self }
    }
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

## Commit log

2024-12-07 feat!: add hierarchal sheets for pcb
    Adds hierarchal sheets for the kicad project. This should allow easier
    collaborative editing.
    [12V_Supply.kicad_sch, Computer_Control.kicad_sch, Low_Current_Supply.kicad_sch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]
2024-12-07 feat: microcontroller on the PCB
    Added the microcontroller and made some basic connections
    [U_Controller.kicad_sch]
2024-12-07 feat: button input initial
    Added initial design for buttons on the PCB
    [Onboard_Control.kicad_sch]
2025-01-09 feat: Laid-out MOSFET ICs
    [Double_Mos.kicad_sch, Vcore_Stage.kicad_sch, Vmem_Stage.kicad_sch]
2025-01-09 feat: added VRM IC
    [VRM_Controller.kicad_sch]
2025-01-09 feat(12V): PCIe connectors, bypass caps, clamping diode circuit
    Draft 1
    [12V_Supply.kicad_sch]
2025-01-09 chore: redirect sub-schematic from untitled to Double_Mos
    [Double_Mos.kicad_sch, Vcore_Stage.kicad_sch]
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2025-01-13 feat: USB-C Port and init of stm32c071
    [U_Controller.kicad_sch]
2025-01-13 feat(schematic): USB on microcontroller
    [U_Controller.kicad_sch]
2025-01-13 feat(schematic): Boot Mode Configuration
    [U_Controller.kicad_sch]
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2025-01-13 feat(schematic): initial 12v design
    [12V_Supply.kicad_sch]
2025-01-13 feat(schematic): initial low current supply
    [Low_Current_Supply.kicad_sch]
2025-01-13 Revert "chore(schematic): Update references"
    This reverts commit 2cda2d22061e90f93ddb38c43ecf32892cd7b43c.
    [12V_Supply.kicad_sch, Double_Mos.kicad_sch, Onboard_Control.kicad_sch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]
2025-01-15 feat(schematic): Microcontroller 48MHz oscillator
    [U_Controller.kicad_sch]
2025-01-15 chore(schematic): Global Labels and Boot Mode Slider
    [U_Controller.kicad_sch]
2025-01-15 feat(schematic): Added Hall Sensor
    [12V_Supply.kicad_sch]
2025-01-15 chore: update project references
    [12V_Supply.kicad_sch, Double_Mos.kicad_sch, Low_Current_Supply.kicad_sch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]
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2025-01-15 feat: new pwm controller symbol
    [VRM_Controller.kicad_sch]
2025-01-15 feat(schematic): USB-C data line OVP
    [U_Controller.kicad_sch]
2025-01-15 refactor(schematic): proper pin mappings
    [U_Controller.kicad_sch]
2025-01-15 refactor(schematic): onboard control connect to microcontroller
    [Onboard_Control.kicad_sch]
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2025-01-16 feat(pcb): add manufacturing constraints
    [gpu-external-power-supply.kicad_pcb]
2025-01-16 chore(schematic): add footprints and datasheets for microcontroller
    [U_Controller.kicad_sch]
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2025-01-16 feat(pcb): onboard control grid
    [Onboard_Control.kicad_sch, gpu-external-power-supply.kicad_pcb]
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2025-01-17 feat(schematic): add onboard display
    [Onboard_Control.kicad_sch]
2025-01-17 feat(schematic): 3.3V global label
    [U_Controller.kicad_sch]
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2025-01-17 feat(pcb): microcontroller and onboard control initial design
    [gpu-external-power-supply.kicad_pcb]
2025-01-17 feat(schematic): set PMBUS address and channel A starting voltage
    [VRM_Controller.kicad_sch]
2025-01-17 feat(schematic): VRM Controller Design
    - 12v Current Sense
    - Digital I/O
    - MOSFET I/0
    - etc
    [VRM_Controller.kicad_sch]
2025-01-17 refactor(schematic): Update VRM Controller Pins
    Updated the VRM controller pinout on the main schematic
    [gpu-external-power-supply.kicad_sch]
2025-01-17 chore(schematic): add global pins
    [U_Controller.kicad_sch]
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2025-01-20 feat(12v): add correct sensor
    [Low_Current_Supply.kicad_sch]
2025-01-20 fix(schematic): 12V Supply & Low Current Supply
    Added proper switching 5V and linear 3.3V ICs.
    [12V_Supply.kicad_sch, Low_Current_Supply.kicad_sch]
2025-01-20 feat(schematic): 12V and Low Current
    Final changes: Added test points and assigned all footprints.
    [12V_Supply.kicad_sch, Low_Current_Supply.kicad_sch]
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2025-01-21 feat(schematic): 12v supply footprints
    [12V_Supply.kicad_sch]
2025-01-21 feat(PCB): 12V supply layout
    [gpu-external-power-supply.kicad_pcb]
2025-01-21 fix(schematic): Minor Style changes to u controller and onboard control
    [Onboard_Control.kicad_sch, U_Controller.kicad_sch]
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2025-01-21 rebase(schematic): Updated Vcore and Vmem pins
    [Vcore_Stage.kicad_sch, Vmem_Stage.kicad_sch, gpu-external-power-supply.kicad_sch]
2025-01-21 feat: add footprint for VRM Controller
    [Vmem_Stage.kicad_sch]
2025-01-21 feet(schematic): Vcore schematic made
    [VRM_Controller.kicad_sch, Vcore_Stage.kicad_sch]
2025-01-21 feat(schematic): Vmem schematic completed, connected controler and stages on main
    [VRM_Controller.kicad_sch, Vcore_Stage.kicad_sch, Vmem_Stage.kicad_sch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]
2025-01-21 feat(schematic): add feedback pins
    [VRM_Controller.kicad_sch, Vcore_Stage.kicad_sch]
2025-01-26 feat(PCB): Vrms for mem and core layed out
    [12V_Supply.kicad_sch, VRM_Controller.kicad_sch, Vmem_Stage.kicad_sch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]
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2025-01-29 chore(footprint): add all missing footprints
2025-01-29 feat(PCB): fix all DRC errors
    [12V_Supply.kicad_sch, Low_Current_Supply.kicad_sch, Onboard_Control.kicad_sch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]
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2025-01-29 chore: last PCB fixes
2025-02-13 fix: stm32c071rb memory mappings
2025-02-13 feat: display init
    Initializes the ssd1306 OLED display and writes a text string to it.
    This is using I2C channel 2 and should be correct based on the hardware
    design.
    [main.rs]
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2025-02-25 fix(firmware): pin I/O reversed
    [main.rs]
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2025-02-25 feat!(firmware): initial VRM controller I2C init
    Adds the traits and implementations for the basic VRM controller
    implementation so that it can be expanded upon in the future. The
    controller on the actual card is not working, but the data should be
    written properly
    [main.rs, vrm_controller.rs]
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2025-03-06 feat: navigation struct
    This stores the current position of the user in the UI as well as
    updates the position. This means that all the position math and error
    checking is handled here and thus is easy to call from other parts in
    the code.
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2025-03-06 feat: inverted text style
    Used for the UI when it is hovering over a box to change (it will have
    text with off pixels instead of on).
    [main.rs]
2025-03-06 fix: stop overflow on display
    [main.rs]
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2025-03-11 refactor: migrate to stm32f4xx-hal
    This includes most of the migration stuff that is necessary.
    * I2C
    * Clocks
    * Timers
    It is missing some pin-reassignments though
    [main.rs]
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2025-04-07 feat(schematic): migrate to stm32f401re
    Migrates to the stm32f401re in the schematic and pin mappings (for the
    most part)
    [Onboard_Control.kicad_sch, U_Controller.kicad_sch]
2025-04-08 chore: remove computer control and clean global references
    [12V_Supply.kicad_sch, Computer_Control.kicad_sch, Onboard_Control.kicad_sch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]
2025-04-09 feat(schematic): refactor main heirarchy
    This commit makes a bunch of changes to how power is delivered on the
    schematic. It also adds the probit header and the i2c output connector
    on the main page of the schematic. Lastly, it changes it so that USB
    power should work and also not power the 5V rail to the mosfet ICs.
    [12V_Supply.kicad_sch, Low_Current_Supply.kicad_sch, U_Controller.kicad_sch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]
2025-04-15 feat: fix pcb changes for 12V and low current supply
    Swapped 5V regulator, added diodes, fixed connectors and general
    placement. Changes to complete list for 12V and low current supply.
    [12V_Supply.kicad_sch, Low_Current_Supply.kicad_sch]
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2025-04-23 feat(schematic): added cooler mounting holes
    added cooler mounting holes to schematic
    changed temp pins to read proper tempurature
    small fixes
    [12V_Supply.kicad_sch, Low_Current_Supply.kicad_sch, Onboard_Control.kicad_sch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]
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2025-04-25 chore: DRC violations fixed
    [U_Controller.kicad_sch]
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2025-04-26 feat(pcb): change feedback connectors to 2x2 instead of 2 1x2s
    [VRM_Controller.kicad_sch]
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2025-05-11 feat: refactor commands
    I really hate how this is done even now, but not exactly sure how to
    make it properly good. I think the send_write and send_read macros are
    doing too much which is making it hard to utilize. I might simplify them
    by making them only do the actual I2C comms with the intention of being
    a better command and read whatever. Anyways, I've spent too much time on
    this and really need to finish other things right now
    [main.rs, vrm_controller.rs]
2025-05-11 chore: fix device in main
    [main.rs]
2025-05-11 fix(pmbus): improper byte ordering
    [vrm_controller.rs]
2025-05-11 revert(b80a97c0): prototype build files
    [gpu-external-power-supply.csv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]
2025-05-16 feat: display support stl
    This is the support column that goes on all 4 corners of the display to
    hold it in place so it does not get broken off or wiggle.
    [DisplayColumn.stl]
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2025-05-17 fix(hardware): fixes for prototype 2
    Fixes:
    * SMBA text orientation wrong
    * Proper pinout for Vmem and Vcore feedback
    * Microcontroller
    * VSSA connection to gnd
    * VRef+ connection to 3.3V
    * VCap connection to 4.7uF to gnd
    * Adjust Mask between Vmem and Vcore Planes
    [U_Controller.kicad_sch, VRM_Controller.kicad_sch]
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2025-05-17 fix: reverse the buffer
    Forgot to include this in the other changes to write stuff
    [vrm_controller.rs]
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2025-05-18 fix: move serial write behind usb polling
    [main.rs]
2025-05-18 fix: forgot to add ReadReady import
    [main.rs]
2025-05-18 fix: wrong channel for iout_oc_fault_limit
    [main.rs]
2025-05-19 fix: load setpoint and limit when in edit mode
    [main.rs]
2025-05-19 fix: disable minimum output voltage
    [main.rs]
